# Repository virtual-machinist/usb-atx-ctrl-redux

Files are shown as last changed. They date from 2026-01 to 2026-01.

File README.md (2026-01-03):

# usb-atx-ctrl-redux

## Rationale

This project is a minified/reduced version of [usb-atx-ctrl](https://github.com/zappanaut/usb-atx-ctrl) project by Zappanaut.

The rationale behind this project is to have a standard PiKVM ATX breakout board installed in the case of the PC being controlled vs replacing it with a custom PCB like done in the aforementioned project.

## Design Choices and Components Used

1. RP2040-Zero (`RZ1`) is not soldered to the PCB directly, but using SMD female pin headers. If needed `RZ1` can be soldered through a set of male pin headers. This might however require offsetting the USB-C socket in the case model.  
2. `SW1` and `SW2` are 4.5x4.5x5mm 90° through-hole miniature tactile push-button switches with distance between the shield and switch terminals is ~2.0mm.

## Assembly

Assembly starts with SMD components, typically resistors, then LEDs, then optorelays. After that RP2040-Zero, tactile switches, then 8P8C socket.  

After PCB assembly it's recommended to print and use a [case](case/README.md) to protect the PCB from accidental damage and electrical shorts.

Assembled photos can be seen under [pictures](pictures/README.md).

## Usage

Setting up the RP2040-Zero is the same as in [usb-atx-ctrl](https://github.com/zappanaut/usb-atx-ctrl) project. The project requires a PC with an [ATX breakout board](https://github.com/pikvm/pikvm/blob/master/docs/atx_board.md) from the PiKVM project or some other solution that exposes a [compatible](https://github.com/pikvm/pikvm/blob/master/docs/atx_board/rj45.jpg) RJ-45 connector. 

## License

The project uses MIT license, except for the case which is [licensed](case/LICENSE) under Creative Commons Attribution 4.0 license ("CC-BY").

## Credits

1. [usb-atx-ctrl](https://github.com/zappanaut/usb-atx-ctrl) project by Zappanaut for most of the schematics and some of the symbols.

2. [Wright-Train-Works](https://github.com/acwright/Wright-Train-Works) project by Aaron Wright for the Amphenol connector STEP file.

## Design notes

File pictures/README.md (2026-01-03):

# Project Photos

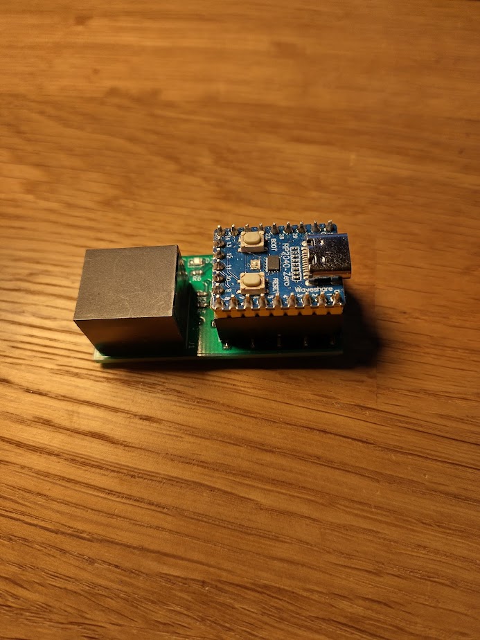
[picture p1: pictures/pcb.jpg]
Populated PCB


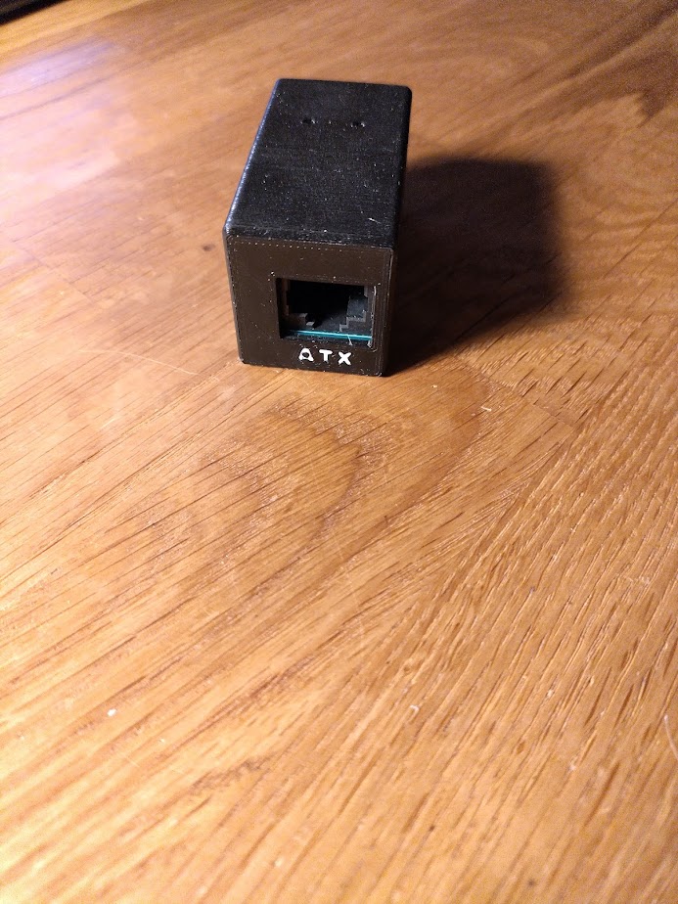
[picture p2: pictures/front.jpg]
Case Front


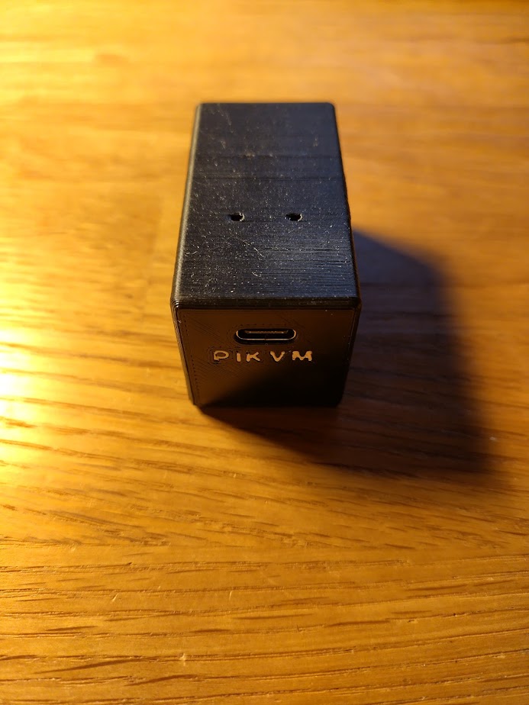
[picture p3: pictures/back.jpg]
Case Back


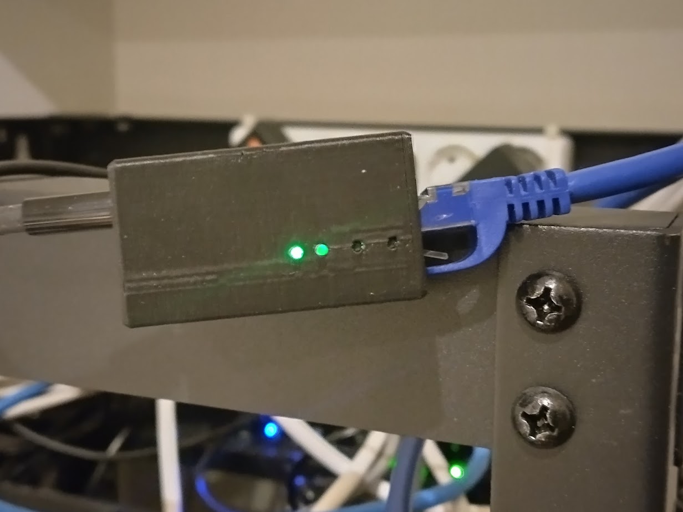
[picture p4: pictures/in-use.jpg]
In use


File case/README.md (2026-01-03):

# usb-atx-ctrl-redux case

## Printing

There are two versions of the case - with signs ([STL](usb-atx-ctrl-redux-signs.stl) and [3MF optimized for multi-material](usb-atx-ctrl-redux-signs.3mf)) and without ([STL](usb-atx-ctrl-redux.stl)).

Printing is done typically by placing the box and the cap on the build plate.

Pretty much any non-conductive material can be used.

The holes for LEDs can be enlarged using a 1.7mm drill bit and a translucent 1.75mm filament can be used as a light guide.

## Modification

The case source is in OpenSCAD. Whether signs for ports are enabled or not is determined by the `signs_enabled` variable.  

To export the STL correctly though a recent OpenSCAD version (2025.x) must be used with lazy unions enabled. 

## License

The case is [licensed](LICENSE) under Creative Commons Attribution 4.0 license ("CC-BY").

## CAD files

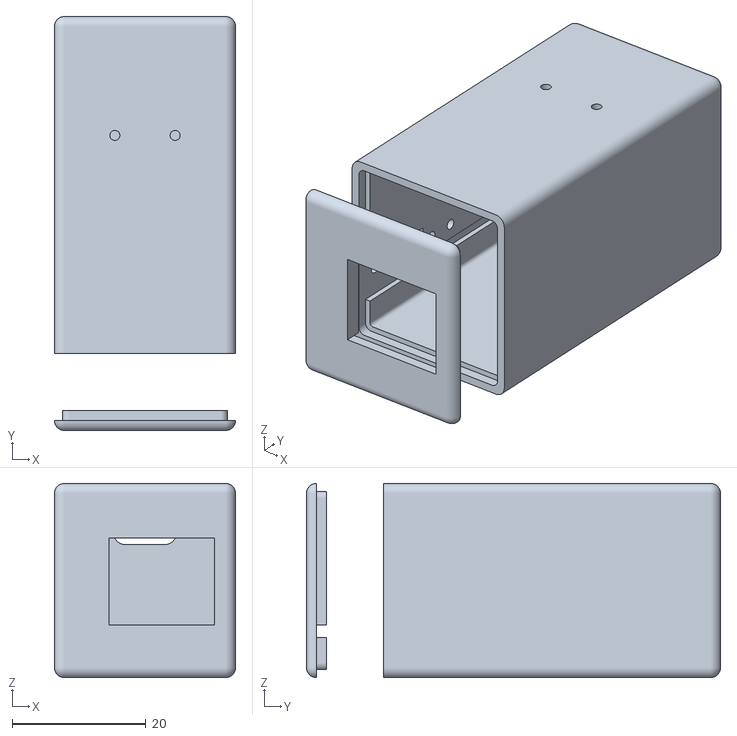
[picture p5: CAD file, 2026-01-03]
case/usb-atx-ctrl-redux.stl
27.0 x 61.8 x 29.0

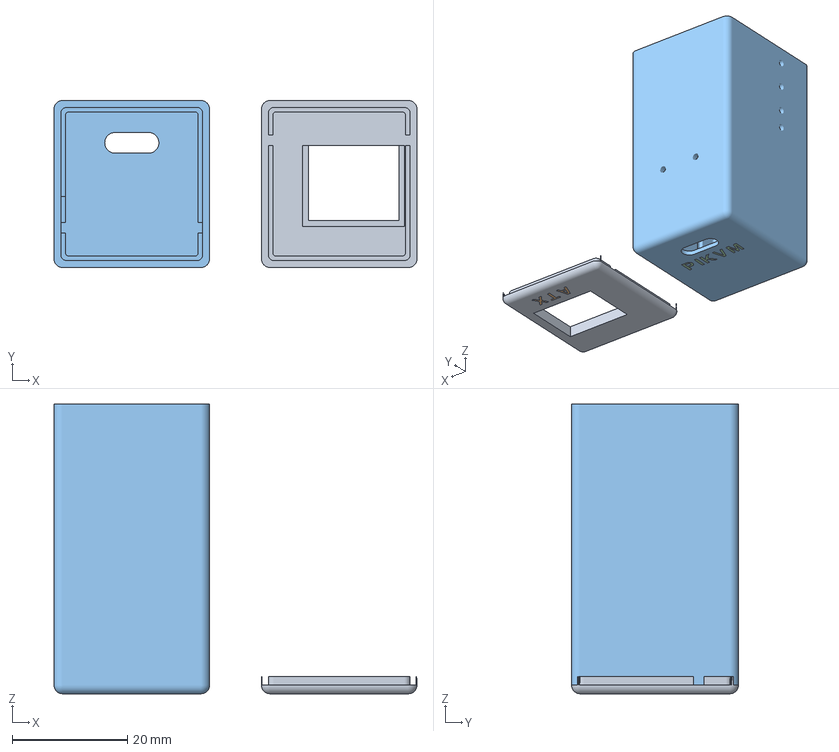
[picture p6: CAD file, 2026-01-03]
case/usb-atx-ctrl-redux-signs.3mf
63.1 x 29.0 x 50.3 mm
Cap
ATX sign
PIKVM sign

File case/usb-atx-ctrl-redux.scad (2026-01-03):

include <BOSL2/std.scad>

$fn = 100;

side_wall_width = 2;
back_wall_width = 1;
front_wall_width = 1;

pcb_width = 24.33;
pcb_depth = 49;
pcb_height = 1.55;

pcb_margin = 0.3;
pcb_inner_height_offset = 4;
pcb_rail_depth = 0.8;

usbc_width = 9.4;
usbc_height = 3.6;
usbc_pcb_offset = 12;

button_hole_diameter = 1.5;
led_hole_diameter = 1.5;

inner_height = 25;

outer_rounding = 1.5;
outer_width = pcb_width + pcb_margin + 2 * side_wall_width - 2 * pcb_rail_depth;
outer_depth = pcb_depth + pcb_margin + back_wall_width;
outer_height = inner_height + 2 * side_wall_width;

inner_width = pcb_width + pcb_margin - 2 * pcb_rail_depth;
inner_depth = pcb_depth + pcb_margin;

cap_rounding = 1;
cap_cutout_height = outer_height - 2 * side_wall_width + 2 * pcb_rail_depth;
cap_cutout_width = outer_width - 2 * side_wall_width + 2 * pcb_rail_depth;
cap_cutout_depth = 1.5;

rj45_cutout_height = 13;
rj45_cutout_width = 15.75;
rj45_right_offset = 2.5;
rj45_lip_height = 1;
rj45_lip_width = 1;

button_cutout_depth = 12;
button_cutout_height = 4.5;

rpi_button_depth_offset = 16;
rpi_center_offset = 4.5;

reset_button_offset = 3.6;
power_button_offset = 9.5;
hdd_led_offset = 15.5;
power_led_offset = 19.8;

signs_enabled = true;
signs_size = 3;
signs_depth = 0.5;

module button_hole() {
  cylinder(h = side_wall_width, d = button_hole_diameter);
}

module led_hole() {
  cylinder(h = side_wall_width + 0.1, d = led_hole_diameter);
}

module pcb() {
  cuboid([pcb_width + pcb_margin, pcb_depth + pcb_margin, pcb_height + pcb_margin]);
}

module box_shell() {
  difference() {
    cuboid(size = [outer_width, outer_depth, outer_height], rounding = outer_rounding, except = [FRONT]);
    fwd(back_wall_width / 2)
      cuboid(size = [inner_width, inner_depth, inner_height], rounding = 0.5, except = [FRONT,BACK]);
  }
}

module cap_cutout() {
  cuboid(size = [cap_cutout_width, cap_cutout_depth, cap_cutout_height], rounding = cap_rounding, except = [FRONT,BACK]);
}

module usbc_hole() {
  rotate([90, 0, 0])
    right((usbc_width - usbc_height) / 2)
      hull() {
        cylinder(h = back_wall_width + 0.2, d = usbc_height);
        left(usbc_width - usbc_height)
          cylinder(h = back_wall_width + 0.2, d = usbc_height);
      }
}

module button_cutout() {
  cuboid([pcb_rail_depth, button_cutout_depth + 0.01, button_cutout_height]);
}

module usb_sign() {
  up(2)
    back((outer_depth - signs_depth) / 2)
      color("red")  
        rotate([180,0,180])
          text3d("PIKVM", h = signs_depth, size = signs_size, spacing = 1.25, orient = BACK, center = true, font = ":style=bold");  
}

module uncapped_box() {
  difference() {
    box_shell();
    fwd(back_wall_width / 2)
      down((inner_height - pcb_height - pcb_margin) / 2 - pcb_inner_height_offset)
          pcb();
    
    back(outer_depth / 2 + 0.1)
      down((inner_height - usbc_height) / 2 - pcb_inner_height_offset - pcb_height - pcb_margin - usbc_pcb_offset)
        usbc_hole();  
    
    fwd((outer_depth - cap_cutout_depth) / 2)
      cap_cutout();
    
    down((inner_height - button_cutout_height) / 2 - pcb_inner_height_offset - pcb_height - pcb_margin)
      fwd((outer_depth - button_cutout_depth) / 2 - cap_cutout_depth)
        left((inner_width + pcb_rail_depth) / 2)
          button_cutout();
    
    back((inner_depth - button_hole_diameter - back_wall_width) / 2 - rpi_button_depth_offset)
      up(inner_height / 2) {
        left(rpi_center_offset)
          button_hole();
        right(rpi_center_offset)
          button_hole();
      }

    down((inner_height - button_cutout_height) / 2 - pcb_inner_height_offset - pcb_height - pcb_margin)
      left(outer_width / 2) {
        rotate([0,90,0]) {
          fwd(outer_depth / 2 - reset_button_offset)
            button_hole();
          fwd(outer_depth / 2 - power_button_offset)
            button_hole();
          fwd(outer_depth / 2 - hdd_led_offset)
            led_hole();
          fwd(outer_depth / 2 - power_led_offset)
            led_hole();
        }
      }
    if (signs_enabled) {
      usb_sign();
    }  
  }
}

module atx_sign() {
  down(10)
    right(2.75)
      fwd(outer_rounding - signs_depth / 2)
        color("red")
          text3d("ATX", h = signs_depth, size = signs_size, spacing = 1.25, orient = FRONT, center = true, font =":style=bold");
}

module cap() {
  difference() {
    union() {
      difference() {
        cuboid(size = [outer_width, outer_rounding + cap_cutout_depth, outer_height], rounding = outer_rounding, except = [BACK]);
        back(cap_cutout_depth) 
          rotate([90,0,0])
            rect_tube(h = cap_cutout_depth, size = [outer_width, outer_height], wall = side_wall_width - pcb_rail_depth, rounding = outer_rounding, irounding = cap_rounding);
        back(cap_cutout_depth / 2) 
          cuboid(size = [cap_cutout_width - 2 * pcb_rail_depth, cap_cutout_depth, cap_cutout_height - 2 * pcb_rail_depth], rounding = 0.5, except = [FRONT,BACK]);
        right(rj45_right_offset)
          down((inner_height - rj45_cutout_height) / 2 - pcb_inner_height_offset - pcb_height - pcb_margin)
            fwd(outer_rounding / 2)
              cuboid([rj45_cutout_width, outer_rounding + 0.1, rj45_cutout_height]);
      }
      right(rj45_right_offset)
        down((inner_height - rj45_cutout_height) / 2 - pcb_inner_height_offset - pcb_height - pcb_margin)
          back(outer_rounding / 2 + 0.25)
            rotate([90,0,0])
              rect_tube(h = outer_rounding + rj45_lip_height, size = [rj45_cutout_width + rj45_lip_width * 2, rj45_cutout_height + rj45_lip_width * 2], wall = rj45_lip_width);
    }
    back(cap_cutout_depth / 2)
      down((inner_height - pcb_height - pcb_margin) / 2 - pcb_inner_height_offset)
        cuboid([pcb_width + pcb_margin, cap_cutout_depth, pcb_height + pcb_margin]);
    if (signs_enabled) {
      atx_sign();
    }
  }
}

uncapped_box();

fwd(outer_depth / 2 + 10)
  cap();

if (signs_enabled) {
  usb_sign();
  fwd(outer_depth / 2 + 10)
    atx_sign();
}  

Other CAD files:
case/usb-atx-ctrl-redux-signs.stl

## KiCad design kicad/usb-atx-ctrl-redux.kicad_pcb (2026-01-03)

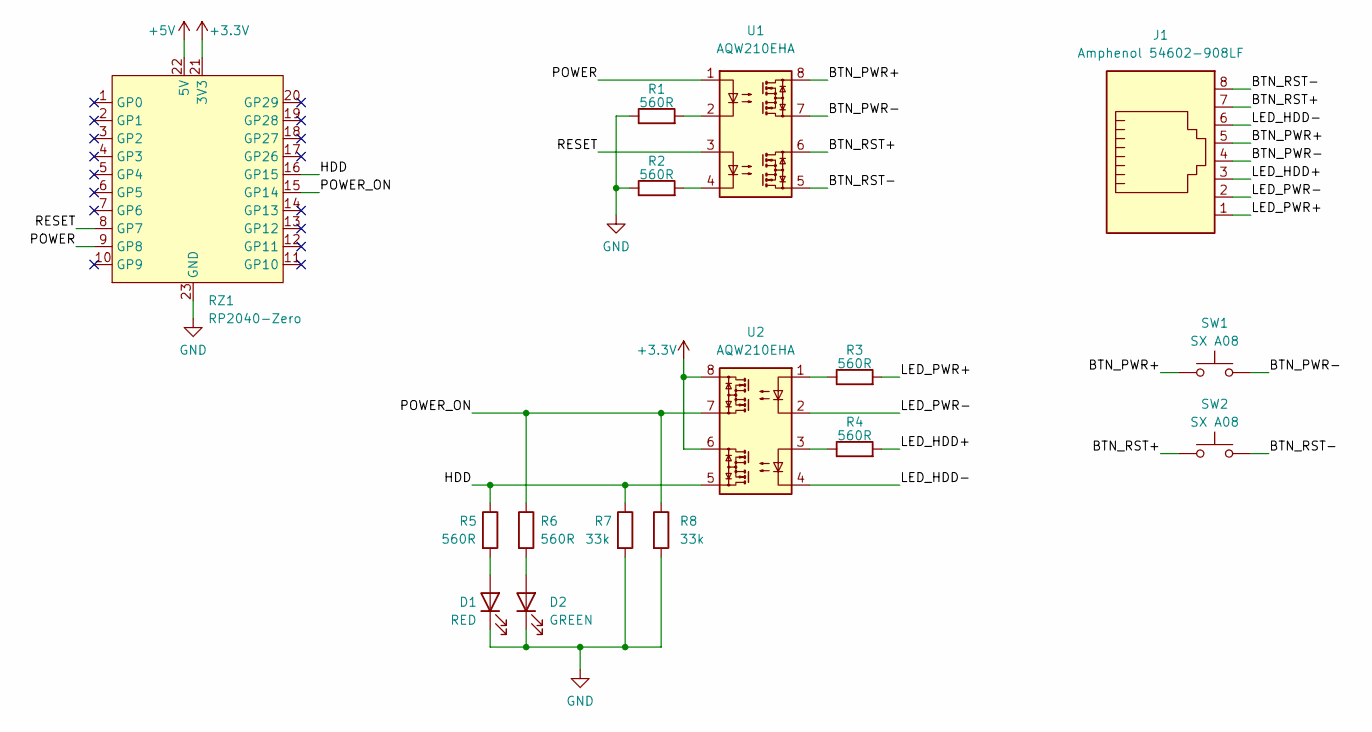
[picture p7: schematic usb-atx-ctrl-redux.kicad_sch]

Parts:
D1: RED; LED_0805_2012Metric_Pad1.15x1.40mm_HandSolder
D2: GREEN; LED_0805_2012Metric_Pad1.15x1.40mm_HandSolder
J1: Amphenol 54602-908LF; RJ45_Amphenol_54602-x08_Horizontal
R1, R2, R3, R4, R5, R6: 560R; R_0603_1608Metric_Pad0.98x0.95mm_HandSolder
R7, R8: 33k; R_0603_1608Metric_Pad0.98x0.95mm_HandSolder
RZ1: RP2040-Zero; RP2040-Zero_SMD
SW1, SW2: SX A08; Button_Switch_SX_A08
U1, U2: AQW210EHA; SMDIP-8_W7.62mm

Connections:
+3.3V: RZ1.21 (3V3), U2.6, U2.8
+5V: RZ1.22 (5V)
/BTN_PWR+: J1.5, SW1.1, U1.8
/BTN_PWR-: J1.4, SW1.2, U1.7
/BTN_RST+: J1.7, SW2.1, U1.6
/BTN_RST-: J1.8, SW2.2, U1.5
/HDD: R5.1, R7.1, RZ1.16 (GP15), U2.5
/LED_HDD+: J1.3, R4.2
/LED_HDD-: J1.6, U2.4
/LED_PWR+: J1.1, R3.2
/LED_PWR-: J1.2, U2.2
/POWER: RZ1.9 (GP8), U1.1
/POWER_ON: R6.1, R8.1, RZ1.15 (GP14), U2.7
/RESET: RZ1.8 (GP7), U1.3
GND: D1.1 (K), D2.1 (K), R1.1, R2.1, R7.2, R8.2, RZ1.23 (GND)
unnamed: D1.2 (A), R5.2
unnamed: D2.2 (A), R6.2
unnamed: R1.2, U1.2
unnamed: R2.2, U1.4
unnamed: R3.1, U2.1
unnamed: R4.1, U2.3

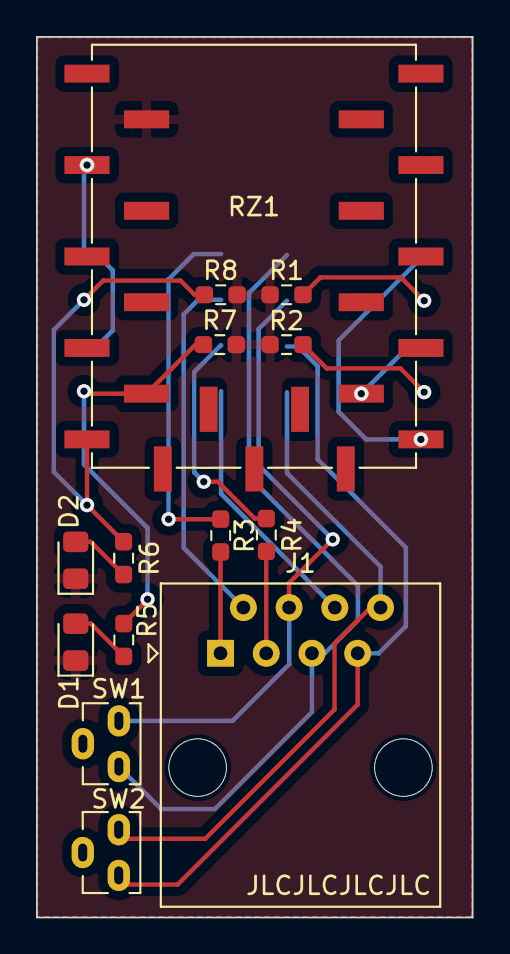
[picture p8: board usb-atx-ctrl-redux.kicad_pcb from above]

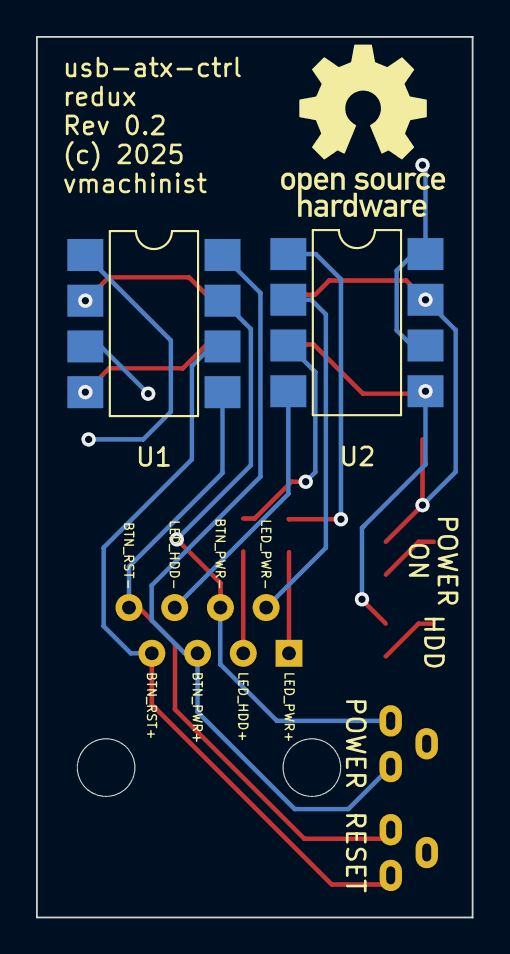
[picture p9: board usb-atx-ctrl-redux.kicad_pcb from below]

Board: 2 copper layers, 24.2 x 48.9 mm, 16 parts (2 on the bottom side), 20 nets.

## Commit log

2026-01-03 KiCad project
    [usb-atx-ctrl-redux.kicad_pcb, usb-atx-ctrl-redux.kicad_sch]
2026-01-03 Add labels
    [usb-atx-ctrl-redux.kicad_pcb]
2026-01-03 Gerber files
    [usb-atx-ctrl-redux-B_Cu.gbl, usb-atx-ctrl-redux-B_Mask.gbs, usb-atx-ctrl-redux-B_Paste.gbp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]
2026-01-03 Fix GPIO assignment, 8P8C footprint, bump to KiCad 8
    [usb-atx-ctrl-redux-B_Cu.gbl, usb-atx-ctrl-redux-B_Mask.gbs, usb-atx-ctrl-redux-B_Paste.gbp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]
2026-01-03 Case project
    [usb-atx-ctrl-redux-signs.3mf, usb-atx-ctrl-redux-signs.stl, usb-atx-ctrl-redux.scad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]
2026-01-03 Move KiCad project to a subdirectory
    [usb-atx-ctrl-redux-B_Cu.gbl, usb-atx-ctrl-redux-B_Mask.gbs, usb-atx-ctrl-redux-B_Paste.gbp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]

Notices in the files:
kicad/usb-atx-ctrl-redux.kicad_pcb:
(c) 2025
